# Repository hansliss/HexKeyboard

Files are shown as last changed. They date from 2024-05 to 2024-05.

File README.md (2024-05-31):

# HexKeyboard

A 25 x 25 keypad with a LED display and many features.

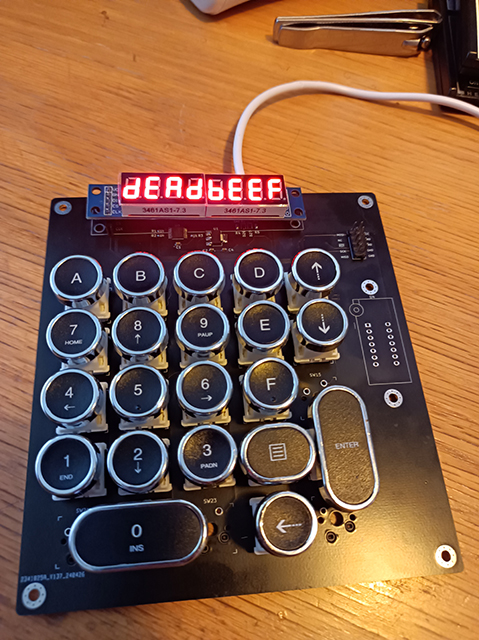
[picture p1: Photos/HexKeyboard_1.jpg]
HexKeyboard_1

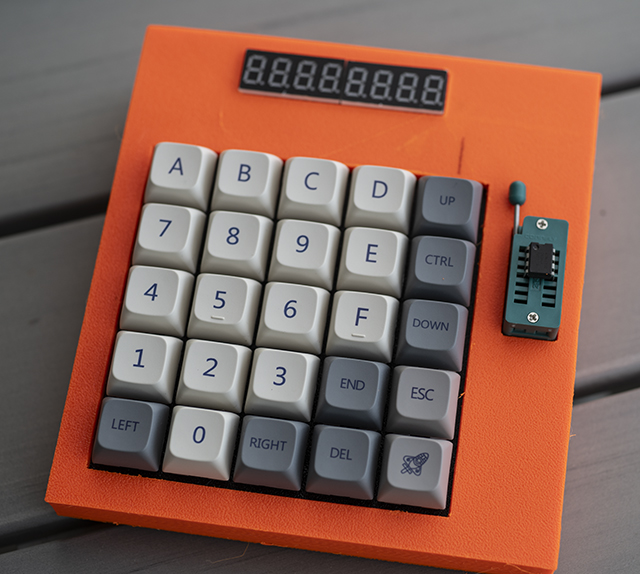
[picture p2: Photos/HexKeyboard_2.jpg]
HexKeyboard_1


* The matrix rows are on pins 4, 12, 6, 7, 23
* The matrix columns are on pins 22, 21, 20, 19, 18

The SD card holder is connected to SPI, plus

* Card Detect = PB0 / pin 17
* Chip Enable = PB4 / pin 8

Note that CD is connected to the RXLED pin, so it will probably collide with serial data.

The display is connected like this:

* CLK = 9
* CS = 10
* DIN = 11

This requires a local max7219.h with the defines modified. Just copy 

### Serial LED pins
If you want to eliminate problems with the two LED pins (see above), you can always just disable the entire functionality, by modifying USBCore.cpp (probably found here: _C:\Users\Yourname\AppData\Local\Arduino15\packages\arduino\hardware\avr\1.8.6\cores\arduino_).

Just comment out everything to do with RXLED and TXLED, and the file will be recompiled upon the next build.

### Misc
The SPI pins for the MAX7219 display aren't actually SPI pins. Still, the max7219 library just bit-bangs the protocol so it doesn't really matter.

If you add an ESP-01/ESP-01S (with the Espressif "AT" firmware, for instance), set it to use 9600 baud
on the serial interface. The default 115200 baud seems a bit too fast.

If you print the case, and want a LED indicator for the ESP-01, print out the included wifiSign model on
a resin printer using transparent resin, then drill a 3.5mm hole roughly 3.7mm below the lower edge of the
display and 13mm to the right of the right edge of the display, insert the transparent plug, and then pour black resin carefully around the symbol (preferably using a syringe and microscope) and cure it with a UV
light.

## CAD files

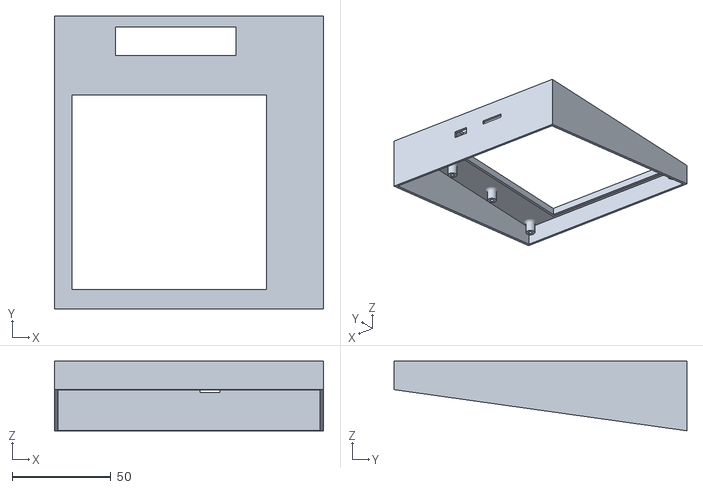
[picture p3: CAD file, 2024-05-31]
Case/case_noZIF.stl
136.2 x 148.1 x 35.2

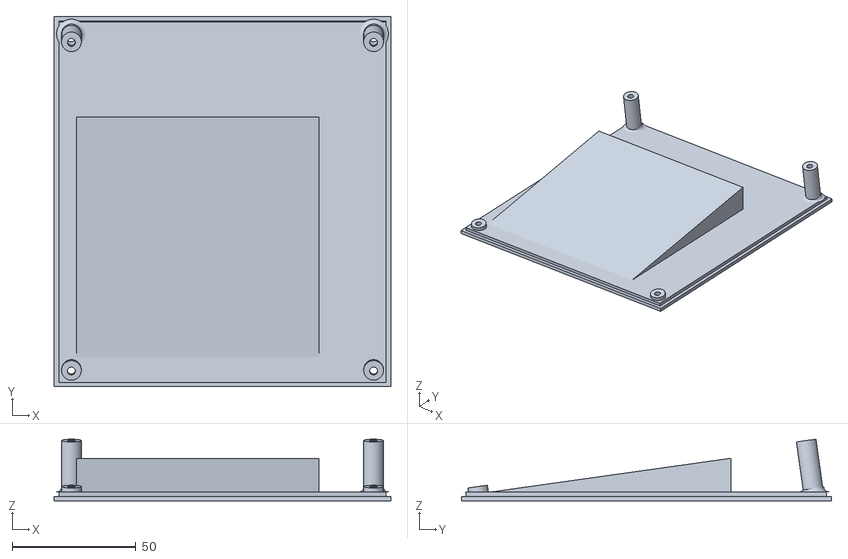
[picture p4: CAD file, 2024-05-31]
Case/caseBottom.stl
136.2 x 149.6 x 24.9

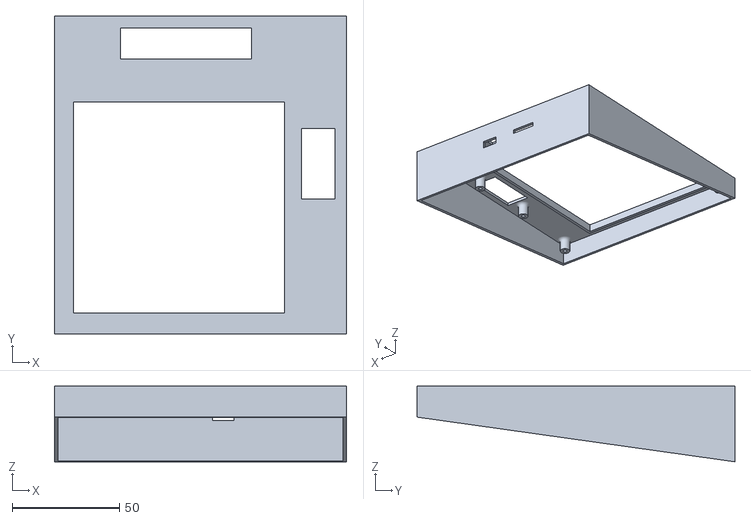
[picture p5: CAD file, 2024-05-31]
Case/case.stl
136.2 x 148.1 x 35.2

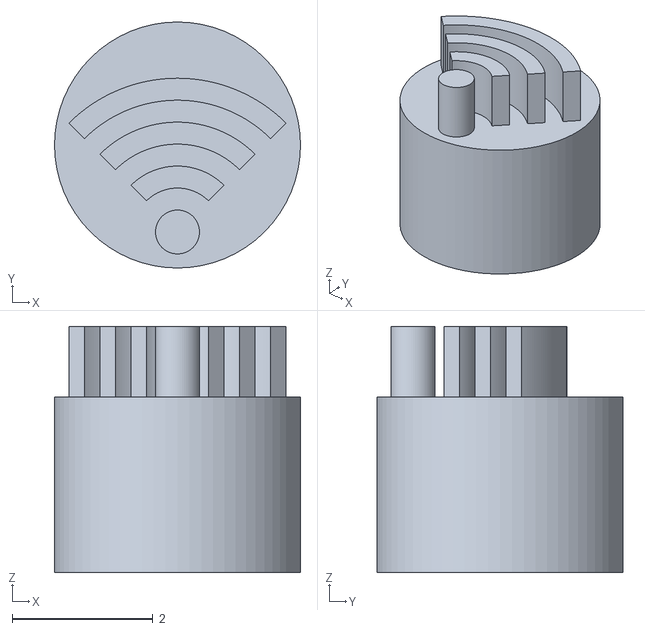
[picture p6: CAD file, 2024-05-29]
Case/wifiSign.stl
3.50 x 3.50 x 3.50

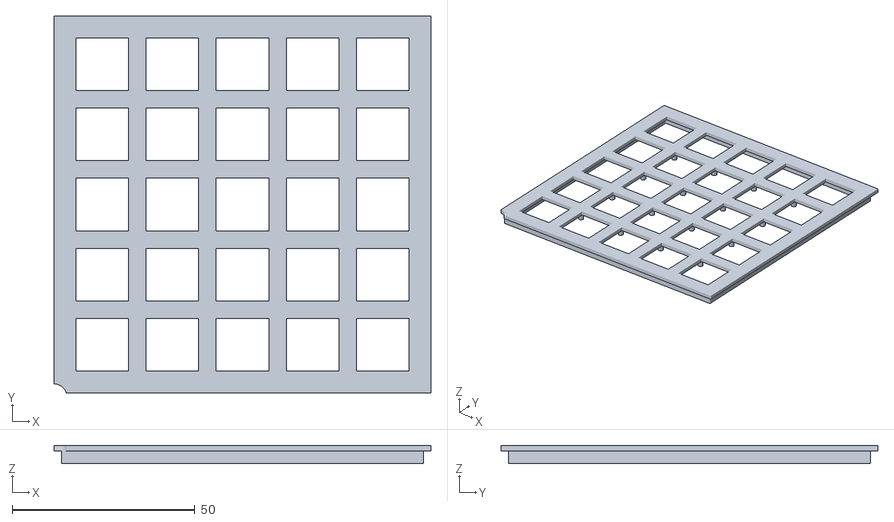
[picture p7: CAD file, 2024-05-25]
Case/faceplate.stl
103.2 x 103.3 x 5.01

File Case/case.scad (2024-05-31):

$fn=16;

include <dimensions.scad>

module screwStandoff() {
    translate([0, 0, - (caseTopStandoffHeight + caseWallThickness / 2 - 0.01)])
        union() {
            difference() {
                cylinder(r = caseTopStandoffOuterRadius, h = caseTopStandoffHeight + 0.01);
                translate([0, 0, -0.01])
                    cylinder(r = caseTopStandoffHoleRadius, h = caseTopStandoffHeight + 0.02);
            }
            translate([0, 0, caseTopStandoffHeight - caseTopStandoffSkirtRadius])
                difference() {
                    cylinder(r = caseTopStandoffOuterRadius + caseTopStandoffSkirtRadius, h = caseTopStandoffSkirtRadius);
                    
                    rotate_extrude(convexity = 10)
                        translate([caseTopStandoffOuterRadius + caseTopStandoffSkirtRadius, 0, 0])
                            circle(r = caseTopStandoffSkirtRadius);
                }
        }
}

union() {
    difference() {
        union() {
            // Top plate
            translate([caseOffsetX, caseOffsetY])
                cube([caseWidth, caseDepth, caseWallThickness], center = true);

                // 4 x top screw standoff
            translate([pcbAbsBLHoleX - pcbCX, - (pcbAbsBLHoleY - pcbCY), 0])
                screwStandoff();
            translate([pcbAbsTLHoleX - pcbCX, - (pcbAbsTLHoleY - pcbCY), 0])
                screwStandoff();
            translate([pcbAbsTRHoleX - pcbCX, - (pcbAbsTRHoleY - pcbCY), 0])
                screwStandoff();
            translate([pcbAbsBRHoleX - pcbCX, - (pcbAbsBRHoleY - pcbCY), 0])
                screwStandoff();

            // 2 x top ZIP screw standoff
            translate([pcbAbsZifTopHoleX - pcbCX, - (pcbAbsZifTopHoleY - pcbCY), 0])
                screwStandoff();
            translate([pcbAbsZifBottomHoleX - pcbCX, - (pcbAbsZifBottomHoleY - pcbCY), 0])
                screwStandoff();
        }
        // Keypad opening
        translate([pcbAbsKeypadCenterX - pcbCX, - (pcbAbsKeypadCenterY - pcbCY), 0])
            cube([caseSwitchPlateOpeningWidth, caseSwitchPlateOpeningDepth, caseWallThickness + 10], center = true);
        
        // Display opening
        translate([pcbAbsDisplayCenterX - pcbCX, - (pcbAbsDisplayCenterY - pcbCY), 00])
            cube([displayWidth, displayDepth, caseWallThickness + 0.2], center = true);
        
        // ZIF socket opening
        translate([pcbAbsZifHoleCenterX - pcbCX, -(pcbAbsZifHoleCenterY - pcbCY), 0])
            cube([caseZifHoleWidth, caseZifHoleDepth, caseWallThickness + 0.02], center = true);
    }
    
    
    translate([caseOffsetX, caseOffsetY])
    difference() {
        union() {
            translate([-(caseWidth / 2 - caseWallThickness / 2), 0, -(caseWallThickness / 2 + caseTopRimHeightUpper / 2 - 0.01 / 2)])
                cube([caseWallThickness, caseDepth, caseTopRimHeightUpper + 0.01], center = true);
            translate([(caseWidth / 2 - caseWallThickness / 2), 0, -(caseWallThickness / 2 + caseTopRimHeightUpper / 2 - 0.01 / 2)])
                cube([caseWallThickness, caseDepth, caseTopRimHeightUpper + 0.01], center = true);
            translate([0, -(caseDepth / 2 - caseWallThickness / 2), -(caseWallThickness / 2 + caseTopRimHeightUpper / 2 - 0.01 / 2)])
                cube([caseWidth, caseWallThickness, caseTopRimHeightUpper + 0.01], center = true);
            difference() {
                translate([0, (caseDepth / 2 - caseWallThickness / 2), -(caseWallThickness / 2 + caseTopRimHeightUpper / 2 - 0.01 / 2)])
                    cube([caseWidth, caseWallThickness, caseTopRimHeightUpper + 0.01], center = true);
                translate([
                    pcbAbsUsbX - pcbCX,
                    caseDepth/2,
                    -(caseWallThickness / 2 + caseTopStandoffHeight + pcbHeight + caseUsbHoleHeight / 2)
                ])
                    cube([caseUsbHoleWidth, 20, caseUsbHoleHeight], center=true);
                translate([
                    pcbAbsSdX - pcbCX,
                    caseDepth/2,
                    -(caseWallThickness / 2 + caseTopStandoffHeight + pcbHeight + caseSdHoleHeight / 2)
                ])
                    cube([caseSdHoleWidth, 20, caseSdHoleHeight], center=true);
            }
        };
        // Cut off the bottom at an angle
        translate([0, 0, -(caseTopRimHeightUpper * 3 / 2 + caseTopRimOffset / 2 + caseTopRimHeightLower)])
            rotate([-caseTopRimAngle, 0, 0])
                cube([caseWidth + 5, caseDepth + 20, caseTopRimHeightUpper * 3], center = true);
    }

    // 4 x inner rim to meet with keypad faceplate
    translate([
        pcbAbsKeypadCenterX - pcbCX + 
        -(caseSwitchPlateOpeningWidth / 2 + caseWallThickness / 2),
        -(pcbAbsKeypadCenterY - pcbCY),
        -(caseWallThickness / 2 + caseSwitchPlateOpeningRimHeight / 2 - 0.015)
    ])
        cube([
            caseWallThickness,
            caseSwitchPlateOpeningDepth + 2 * caseWallThickness,
            caseSwitchPlateOpeningRimHeight + 0.01
        ], center = true);
    translate([
        pcbAbsKeypadCenterX - pcbCX + 
        (caseSwitchPlateOpeningWidth / 2 + caseWallThickness / 2),
        -(pcbAbsKeypadCenterY - pcbCY),
        -(caseWallThickness / 2 + caseSwitchPlateOpeningRimHeight / 2 - 0.015)
    ])
        cube([
            caseWallThickness,
            caseSwitchPlateOpeningDepth + 2 * caseWallThickness,
            caseSwitchPlateOpeningRimHeight + 0.01
        ], center = true);
    translate([
        pcbAbsKeypadCenterX - pcbCX,
        -(pcbAbsKeypadCenterY - pcbCY)
        + (caseSwitchPlateOpeningDepth / 2 + caseWallThickness / 2),
        -(caseWallThickness / 2 + caseSwitchPlateOpeningRimHeight / 2 - 0.015)
    ])
        cube([
            caseSwitchPlateOpeningWidth + 2 * caseWallThickness,
            caseWallThickness,
            caseSwitchPlateOpeningRimHeight + 0.01
        ], center = true);
    translate([
        pcbAbsKeypadCenterX - pcbCX,
        -(pcbAbsKeypadCenterY - pcbCY)
        - (caseSwitchPlateOpeningDepth / 2 + caseWallThickness / 2),
        -(caseWallThickness / 2 + caseSwitchPlateOpeningRimHeight / 2 - 0.015)
    ])
        cube([
            caseSwitchPlateOpeningWidth + 2 * caseWallThickness,
            caseWallThickness,
            caseSwitchPlateOpeningRimHeight + 0.01
        ], center = true);
        

}

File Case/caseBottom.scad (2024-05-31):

$fn=128;

include <dimensions.scad>

module screwStandoffLow() {
    translate([0, 0, caseWallThickness / 2])
        rotate([caseTopRimAngle, 0, 0])
            cylinder(r=caseBottomStandoffOuterRadius, h=caseBottomShortStandoffHeight);
}

module screwStandoffHigh() {
    translate([0, 0, caseWallThickness / 2])
        rotate([caseTopRimAngle, 0, 0])
            cylinder(r=caseBottomStandoffOuterRadius, h=caseBottomTallStandoffHeight);
}

module screwHoleLow() {
    translate([0, 0, -caseWallThickness / 2])
        rotate([caseTopRimAngle, 0, 0])
            union() {
                cylinder(r=caseBottomStandoffHoleRadius, h=4 + caseWallThickness + 0.2);
                translate([0, 0, -(caseWallThickness / 2 + 0.2)])
                    cylinder(r=caseBottomStandoffInnerRadius, h=caseBottomShortStandoffHeight);
            }
}

module screwHoleHigh() {
    translate([0, 0, -caseWallThickness / 2])
        rotate([caseTopRimAngle, 0, 0])
            union() {
                cylinder(r=caseBottomStandoffHoleRadius, h=caseBottomTallStandoffHeight + caseWallThickness + 0.2);
                translate([0, 0, -(caseWallThickness / 2 + 0.2)])
                    cylinder(r=caseBottomStandoffInnerRadius, h=caseBottomTallStandoffHeight);
            }
}

difference() {
    union() {
        translate([caseOffsetX, caseOffsetY])
            union() {
                cube([caseWidth, caseDepth / cos(caseTopRimAngle), caseWallThickness], center = true);
                intersection() {
                    translate([0, 0, caseWallThickness - 0.01])
                        cube([caseWidth - (2 * caseWallThickness + 0.2), 5 + caseDepth - (2 * caseWallThickness + 0.2), caseWallThickness], center = true);
                    translate([0, 0, caseWallThickness / 2])
                        rotate([caseTopRimAngle, 0, 0])
                            cube([caseWidth - (2 * caseWallThickness + 0.2), (caseDepth - (2 * caseWallThickness + 0.2)), 50], center = true);
            }
        }
        // Keypad backing
        intersection() {
            translate([pcbAbsKeypadCenterX - pcbCX, - (pcbAbsKeypadCenterY - pcbCY), caseWallThickness * 1.5 + (caseBottomTallStandoffHeight - 1.5) / 2 - 0.01])
                cube([caseSwitchPlateOpeningWidth, caseSwitchPlateOpeningDepth, caseBottomTallStandoffHeight - 1.5], center = true);
            translate([0, 0, 0])
                rotate([caseTopRimAngle, 0, 0])
                    cube([caseWidth, caseDepth, caseBottomTallStandoffHeight], center = true);
        }
        
        // 4 x top screw standoff
        translate([(pcbAbsBLHoleX - pcbCX), - (pcbAbsBLHoleY - pcbCY) / cos(caseTopRimAngle), 0])
            screwStandoffLow();
        translate([(pcbAbsTLHoleX - pcbCX), - (pcbAbsTLHoleY - pcbCY) / cos(caseTopRimAngle), 0])
            union() {
                screwStandoffHigh();
                translate([0, 0, caseWallThickness * 1.5 - 0.01])
                difference() {
                    cylinder(r = caseBottomStandoffOuterRadius + caseBottomStandoffSkirtRadius, h = caseBottomStandoffSkirtRadius);
                    translate([0, 0, caseBottomStandoffSkirtRadius])
                        rotate_extrude(convexity = 10)
                            translate([caseBottomStandoffOuterRadius + caseBottomStandoffSkirtRadius, 0, 0])
                                circle(r = caseBottomStandoffSkirtRadius);
                }
            }
        translate([(pcbAbsTRHoleX - pcbCX), - (pcbAbsTRHoleY - pcbCY) / cos(caseTopRimAngle), 0])
            union() {
                screwStandoffHigh();
                translate([0, 0, caseWallThickness * 1.5 - 0.01])
                difference() {
                    cylinder(r = caseBottomStandoffOuterRadius + caseBottomStandoffSkirtRadius, h = caseBottomStandoffSkirtRadius);
                    translate([0, 0, caseBottomStandoffSkirtRadius])
                        rotate_extrude(convexity = 10)
                            translate([caseBottomStandoffOuterRadius + caseBottomStandoffSkirtRadius, 0, 0])
                                circle(r = caseBottomStandoffSkirtRadius);
                }
            }
        translate([(pcbAbsBRHoleX - pcbCX), - (pcbAbsBRHoleY - pcbCY) / cos(caseTopRimAngle), 0])
            screwStandoffLow();
    }
    // 4 x top screw standoff
    translate([(pcbAbsBLHoleX - pcbCX), - (pcbAbsBLHoleY - pcbCY) / cos(caseTopRimAngle), 0])
        screwHoleLow();
    translate([(pcbAbsTLHoleX - pcbCX), - (pcbAbsTLHoleY - pcbCY) / cos(caseTopRimAngle), 0])
        screwHoleHigh();
    translate([(pcbAbsTRHoleX - pcbCX), - (pcbAbsTRHoleY - pcbCY) / cos(caseTopRimAngle), 0])
        screwHoleHigh();
    translate([(pcbAbsBRHoleX - pcbCX), - (pcbAbsBRHoleY - pcbCY) / cos(caseTopRimAngle), 0])
        screwHoleLow();
    
}

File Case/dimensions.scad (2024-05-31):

facePlateSwitchHoleWidth=14.4;
facePlateSwitchHoleDepth=14.4;
facePlateThickness=1.5;
facePlateTop=5;

facePlateSwitchesX = 5;
facePlateSwitchesY = 5;

facePlateSwitchDistX=19.21;
facePlateSwitchDistY=19.22;

facePlateSwitchOuterMargin=4;

facePlateOuterMargin=2;

facePlateWidth = (facePlateSwitchesX - 1) * facePlateSwitchDistX + facePlateSwitchHoleWidth + 2 * facePlateSwitchOuterMargin;
facePlateDepth = (facePlateSwitchesY - 1) * facePlateSwitchDistY + facePlateSwitchHoleDepth + 2 * facePlateSwitchOuterMargin;

facePlateDistanceFromBLScrewHoleX = 0;
facePlateDistanceFromBLScrewHoleY = 1;

pcbAbsLeftEdgeX = 31.94;
pcbAbsTopEdgeY = 38.2;
pcbAbsRightEdgeX = 164.1;
pcbAbsBottomEdgeY = 182.34;

pcbAbsTLHoleX = 36.94;
pcbAbsTLHoleY = 43.2;

pcbAbsBLHoleX = 36.94;
pcbAbsBLHoleY = 177.34;

pcbAbsTRHoleX = 159.1;
pcbAbsTRHoleY = 43.2;

pcbAbsBRHoleX = 159.1;
pcbAbsBRHoleY = 177.34;

pcbKeySwitchCenterOffsetX = -2.54;
pcbKeySwitchCenterOffsetY = 5.08;

pcbAbsKeypadCenterX = 90.555 + pcbKeySwitchCenterOffsetX;
pcbAbsKeypadCenterY = 120.25 + pcbKeySwitchCenterOffsetY;

pcbAbsZifTopHoleX = 152.82;
pcbAbsZifTopHoleY = 83.49;

pcbAbsZifBottomHoleX = 152.82;
pcbAbsZifBottomHoleY = 126.96;

pcbAbsZifHoleCenterX = 152.9;
pcbAbsZifHoleCenterY = 105.05;

pcbAbsUsbX = 108.6025;
pcbAbsSdX = 81.94;

pcbAbsDisplayCenterX = 40 + 51.33;
pcbAbsDisplayCenterY = 48.935;

pcbCX = (pcbAbsLeftEdgeX + pcbAbsRightEdgeX) / 2;
pcbCY = (pcbAbsTopEdgeY + pcbAbsBottomEdgeY) / 2;

pcbWidth = pcbAbsRightEdgeX - pcbAbsLeftEdgeX;
pcbDepth = pcbAbsBottomEdgeY - pcbAbsTopEdgeY;
pcbHeight = 1.6;

displayWidth = 61;
displayDepth = 14.5;

caseWallThickness = 1.8;

caseSwitchMargin = 3.5;
caseSwitchPlateOpeningWidth = (facePlateSwitchesX - 1) * facePlateSwitchDistX + facePlateSwitchHoleWidth + 2 * caseSwitchMargin;
caseSwitchPlateOpeningDepth = (facePlateSwitchesY - 1) * facePlateSwitchDistY + facePlateSwitchHoleDepth + 2 * caseSwitchMargin;

caseSwitchPlateOpeningRimHeight = 3;

caseSwitchPlateOpeningPosX = pcbAbsKeypadCenterX - pcbCX;
caseSwitchPlateOpeningPosy = pcbAbsKeypadCenterY - pcbCY;

caseMarginTop = 0.2;
caseMarginBottom = 1.2;
caseMarginLeft = 1.2;
caseMarginRight = 1.2;
caseWidth = pcbWidth + caseMarginLeft + caseMarginRight + 2 * caseWallThickness;
caseDepth = pcbDepth + caseMarginTop + caseMarginBottom + 2 * caseWallThickness;
caseOffsetY = (caseMarginTop - caseMarginBottom)/2;
caseOffsetX = (caseMarginRight - caseMarginLeft)/2;

caseTopStandoffHeight = caseSwitchPlateOpeningRimHeight + facePlateTop;
caseTopStandoffHoleRadius = 1.25;
caseTopStandoffOuterRadius = 3;
caseTopStandoffSkirtRadius = 2;

caseZifHoleWidth = 15.5;
caseZifHoleDepth = 33;

caseTopRimAngle = 8;
caseTopRimOffset = tan(caseTopRimAngle) * caseDepth;
caseTopRimHeightLower = caseTopStandoffHeight + 6;
caseTopRimHeightUpper = caseTopStandoffHeight + 6 + caseTopRimOffset;

caseUsbHoleWidth = 10;
caseUsbHoleHeight = 4.5;

caseSdHoleWidth = 15.5;
caseSdHoleHeight = 2.5;

caseBottomTallStandoffHeight = 22.8;
caseBottomShortStandoffHeight = 4;
caseBottomStandoffOuterRadius = 4;
caseBottomStandoffInnerRadius = 3;
caseBottomStandoffHoleRadius = 1.6;
caseBottomStandoffSkirtRadius = caseTopStandoffSkirtRadius;

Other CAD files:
Case/faceplate.scad
Case/wifiSign.scad

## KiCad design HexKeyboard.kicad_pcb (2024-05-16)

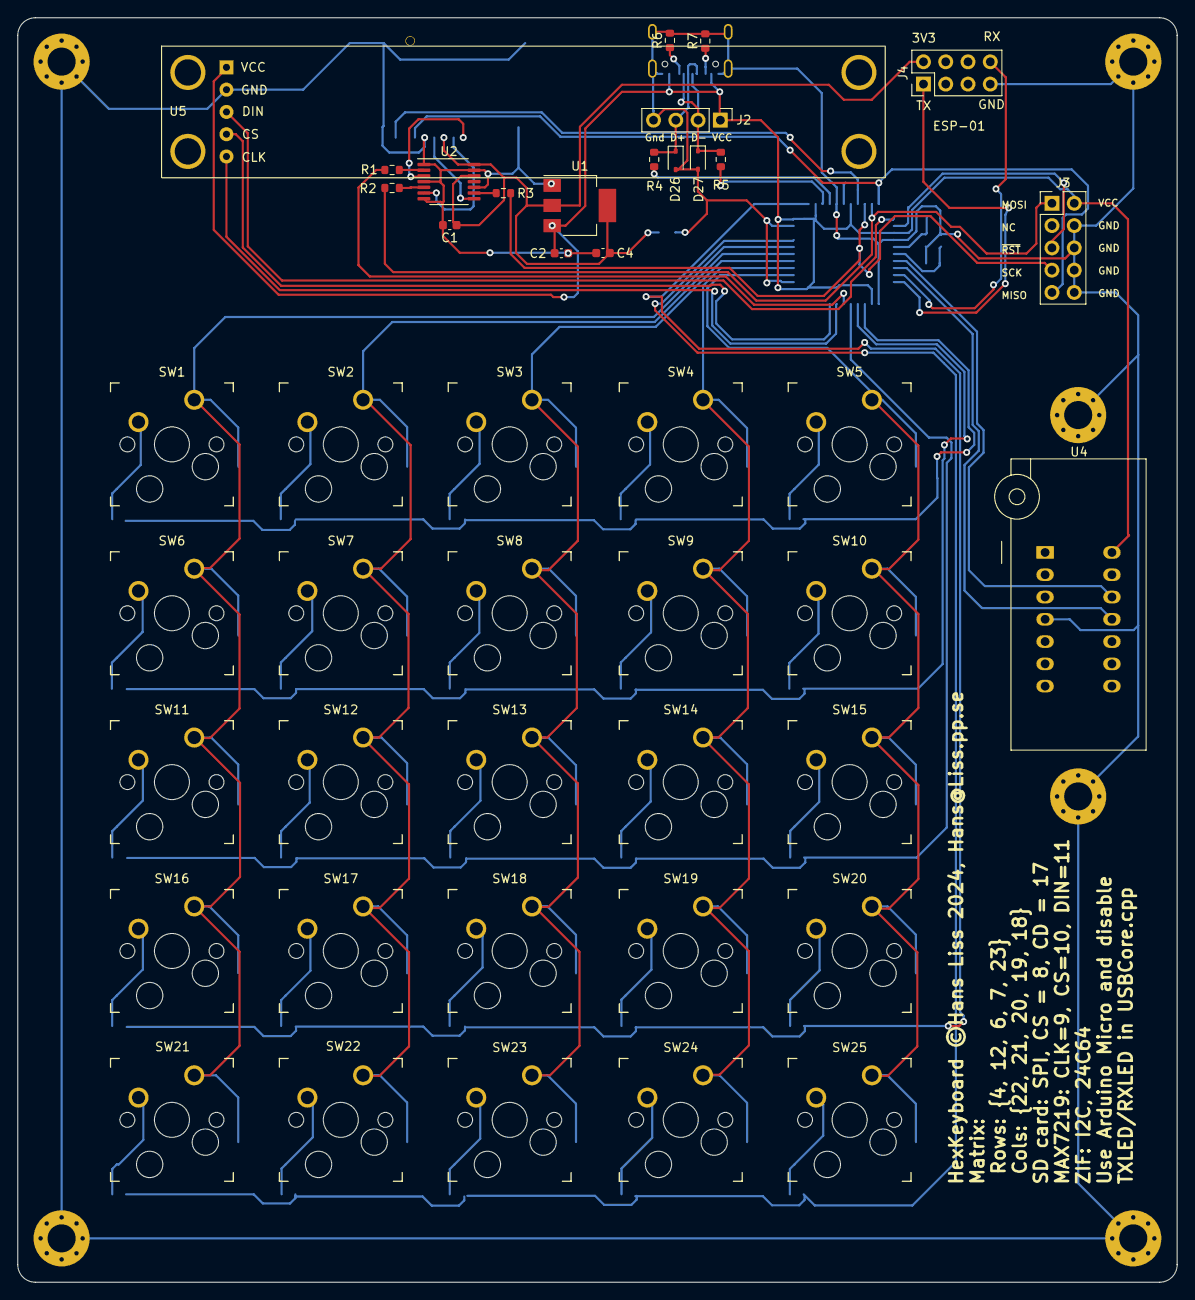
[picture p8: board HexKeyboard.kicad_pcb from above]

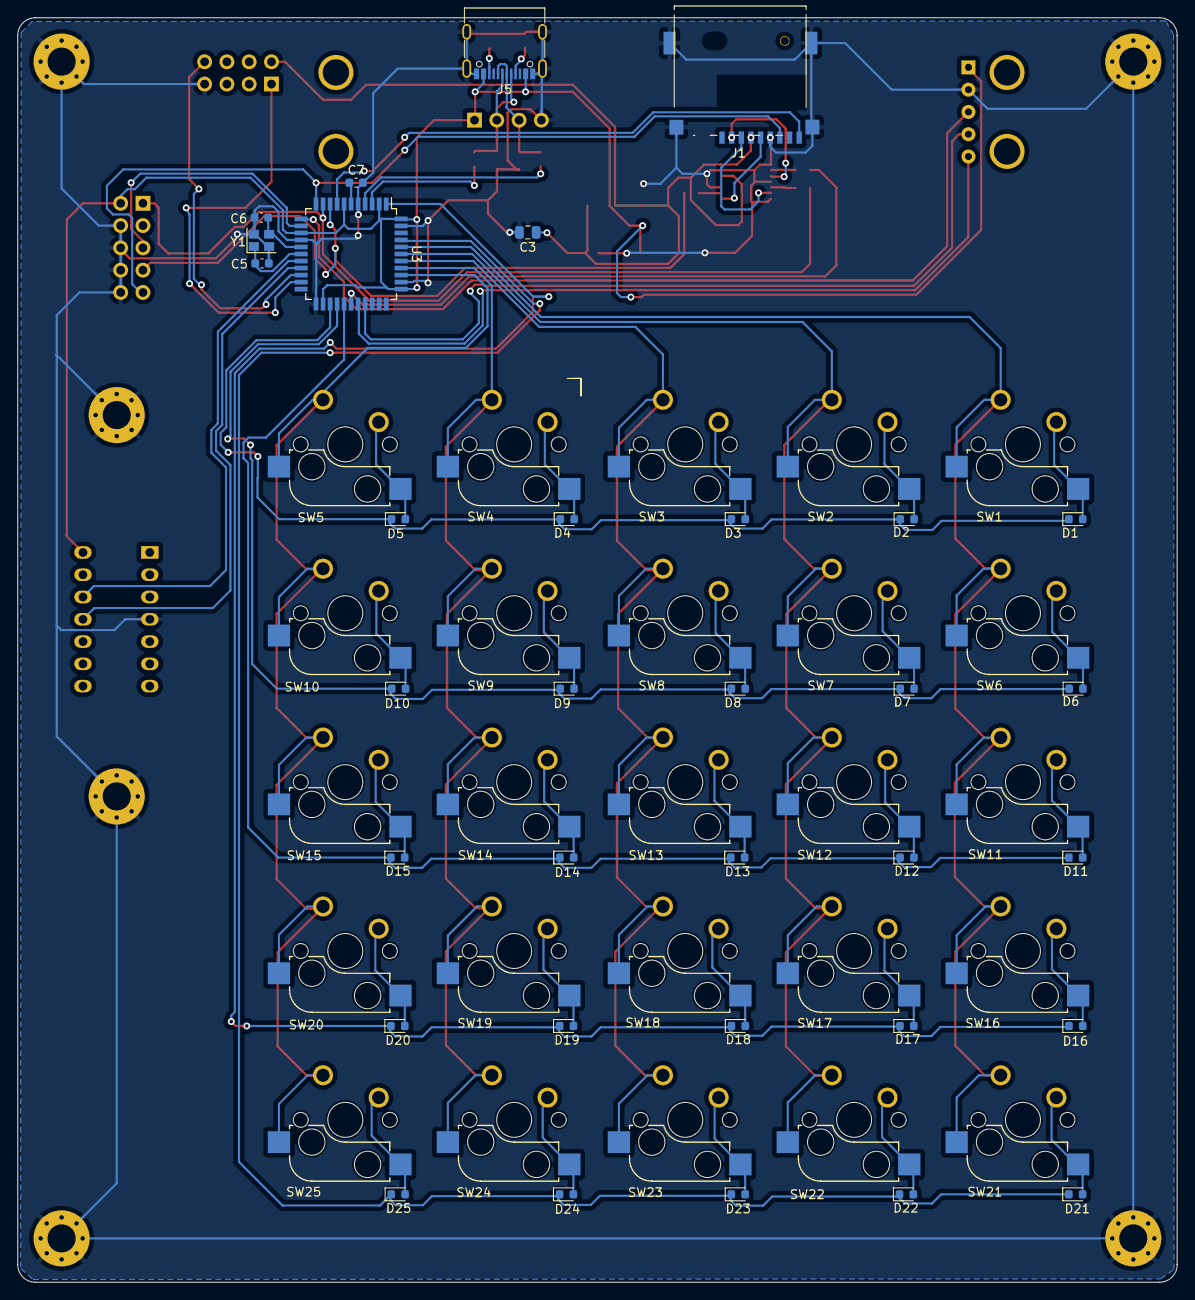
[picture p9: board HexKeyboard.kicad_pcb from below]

Board: 2 copper layers, 132.2 x 144.1 mm, 83 parts (33 on the bottom side), 66 nets.

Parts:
C1, C2, C4: 100nF; C_0603_1608Metric
C3: 10uF/10V; C_0805_2012Metric
C5, C6: 9pF; C_0603_1608Metric
C7: 1uF; C_0603_1608Metric
D1, D2, D3, D4, D5, D6, D7, D8, D9, D10, D11, D12, D13, D14, D15, D16, D17, D18, D19, D20, D21, D22, D23, D24, D25: D; D_0603_1608Metric
D26, D27: BZX384-xxx; D_SOD-323
H1, H2, H3, H4, H5, H6: MountingHole_Pad; MountingHole_3.2mm_M3_Pad_Via
J1: Micro_SD_Card; GCT_MEM2075
J2: Conn_01x04; PinHeader_1x04_P2.54mm_Vertical
J3: Conn_02x04_Odd_Even; PinHeader_2x05_P2.54mm_Vertical
J4: Conn_02x04_Odd_Even; PinHeader_2x04_P2.54mm_Vertical
J5: USB_A; USB_C_Receptacle_G-Switch_GT-USB-7010ASV
R1, R2, R3: 3k3; R_0603_1608Metric
R4, R5: 22; R_0603_1608Metric
R6, R7: 5k6; R_0603_1608Metric
SW1: SW_1; Kailh_socket_MX_optional_compatible
SW2: SW_2; Kailh_socket_MX_optional_compatible
SW3: SW_3; Kailh_socket_MX_optional_compatible
SW4: SW_4; Kailh_socket_MX_optional_compatible
SW5: SW_5; Kailh_socket_MX_optional_compatible
SW6: SW_6; Kailh_socket_MX_optional_compatible
SW7: SW_7; Kailh_socket_MX_optional_compatible
SW8: SW_8; Kailh_socket_MX_optional_compatible
SW9: SW_9; Kailh_socket_MX_optional_compatible
SW10: SW_10; Kailh_socket_MX_optional_compatible
SW11: SW_11; Kailh_socket_MX_optional_compatible
SW12: SW_12; Kailh_socket_MX_optional_compatible
SW13: SW_13; Kailh_socket_MX_optional_compatible
SW14: SW_14; Kailh_socket_MX_optional_compatible
SW15: SW_15; Kailh_socket_MX_optional_compatible
SW16: SW_16; Kailh_socket_MX_optional_compatible
SW17: SW_17; Kailh_socket_MX_optional_compatible
SW18: SW_18; Kailh_socket_MX_optional_compatible
SW19: SW_19; Kailh_socket_MX_optional_compatible
SW20: SW_20; Kailh_socket_MX_optional_compatible
SW21: SW_21; Kailh_socket_MX_optional_compatible
SW22: SW_22; Kailh_socket_MX_optional_compatible
SW23: SW_23; Kailh_socket_MX_optional_compatible
SW24: SW_24; Kailh_socket_MX_optional_compatible
SW25: SW_25; Kailh_socket_MX_optional_compatible
U1: AMS1117-3.3; SOT-223-3_TabPin2
U2: 74LVC125; TSSOP-14_4.4x5mm_P0.65mm
U3: ATmega32U4-AU; TQFP-44_10x10mm_P0.8mm
U4: AT24CS64-XHM; DIP_Socket-14_W4.3_W5.08_W7.62_W10.16_W10.9_3M_214-3339-00-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
U5: MAX7219; Display_x8_MAX7219
Y1: 16MHz; Crystal_SMD_2520-4Pin_2.5x2.0mm

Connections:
+3.3V: C1.1, C3.1, C4.1, J1.4 (VDD), J4.2, U1.2 (VO), U2.12, U2.14 (VCC)
/CD: J1.9 (DET), U3.8 (PB0)
/CE: R1.2, U3.28 (PB4)
/MISO: J1.7 (DAT0), J3.9, U3.11 (PB3)
/MOSI: J3.1, R2.2, U3.10 (PB2)
/RX: J4.8, U3.20 (PD2)
/SCK: J3.7, R3.2, U3.9 (PB1)
/SCL: U3.18 (PD0), U4.12 (SCL)
/SDA: U3.19 (PD1), U4.11 (SDA)
/TX: J4.1, U3.21 (PD3)
/~RESET: J3.5, U3.13 (~RESET)
COL0: SW1.1, SW6.1, SW11.1, SW16.1, SW21.1, U3.40 (PF1)
COL1: SW2.1, SW7.1, SW12.1, SW17.1, SW22.1, U3.39 (PF4)
COL2: SW3.1, SW8.1, SW13.1, SW18.1, SW23.1, U3.38 (PF5)
COL3: SW4.1, SW9.1, SW14.1, SW19.1, SW24.1, U3.37 (PF6)
COL4: SW5.1, SW10.1, SW15.1, SW20.1, SW25.1, U3.36 (PF7)
GND: C1.2, C2.2, C3.2, C4.2, C5.2, C6.2, C7.2, D26.2 (A), D27.2 (A), H1.1, H2.1, H3.1, H4.1, H5.1, H6.1, J1.6 (VSS), J1.10 (SHIELD), J2.4, J3.4, J3.6, J3.8, J3.10, J4.7, J5.A1 (GND), J5.A12 (GND), J5.B1 (GND), J5.B12 (GND), J5.S1 (SHIELD), R6.2, R7.2, U1.1 (GND), U2.1, U2.4, U2.7 (GND), U2.10, U2.13, U3.5 (UGND), U3.15 (GND), U3.23 (GND), U3.35 (GND), U3.43 (GND), U4.4 (GND), U5.2 (GND), Y1.2, Y1.4
unnamed: D1.2 (A), SW1.2
unnamed: D2.2 (A), SW2.2
unnamed: D3.2 (A), SW3.2
unnamed: D4.2 (A), SW4.2
unnamed: D5.2 (A), SW5.2
unnamed: D6.2 (A), SW6.2
unnamed: D7.2 (A), SW7.2
unnamed: D8.2 (A), SW8.2
unnamed: D9.2 (A), SW9.2
unnamed: D10.2 (A), SW10.2
unnamed: D11.2 (A), SW11.2
unnamed: D12.2 (A), SW12.2
unnamed: D13.2 (A), SW13.2
unnamed: D14.2 (A), SW14.2
unnamed: D15.2 (A), SW15.2
unnamed: D16.2 (A), SW16.2
unnamed: D17.2 (A), SW17.2
unnamed: D18.2 (A), SW18.2
unnamed: D19.2 (A), SW19.2
unnamed: D20.2 (A), SW20.2
unnamed: D21.2 (A), SW21.2
unnamed: D22.2 (A), SW22.2
unnamed: D23.2 (A), SW23.2
unnamed: D24.2 (A), SW24.2
unnamed: D25.2 (A), SW25.2
unnamed: D26.1 (K), J2.3, J5.A6 (D+), J5.B6 (D+), R4.2
unnamed: D27.1 (K), J2.2, J5.A7 (D-), J5.B7 (D-), R5.2
unnamed: J1.5 (CLK), U2.8
unnamed: J1.3 (CMD), U2.6
unnamed: J1.2 (DAT3/CD), U2.3
unnamed: J5.A5 (CC1), R6.1
unnamed: J5.B5 (CC2), R7.1
unnamed: R1.1, U2.2
unnamed: R2.1, U2.5
unnamed: R3.1, U2.9
unnamed: R4.1, U3.4 (D+)
unnamed: R5.1, U3.3 (D-)
unnamed: U3.29 (PB5), U5.5 (CLK)
unnamed: U3.30 (PB6), U5.4 (CS)
unnamed: U3.12 (PB7), U5.3 (DIN)
unnamed: C7.1, U3.6 (UCAP)
unnamed: C5.1, U3.17 (XTAL1), Y1.1
unnamed: C6.1, U3.16 (XTAL2), Y1.3
ROW0: D1.1 (K), D2.1 (K), D3.1 (K), D4.1 (K), D5.1 (K), U3.25 (PD4)
ROW1: D6.1 (K), D7.1 (K), D8.1 (K), D9.1 (K), D10.1 (K), U3.26 (PD6)
ROW2: D11.1 (K), D12.1 (K), D13.1 (K), D14.1 (K), D15.1 (K), U3.27 (PD7)
ROW3: D16.1 (K), D17.1 (K), D18.1 (K), D19.1 (K), D20.1 (K), U3.1 (PE6)
ROW4: D21.1 (K), D22.1 (K), D23.1 (K), D24.1 (K), D25.1 (K), U3.41 (PF0)
VCC: C2.1, J2.1, J3.2, J5.A4 (VBUS), J5.A9 (VBUS), J5.B4 (VBUS), J5.B9 (VBUS), U1.3 (VI), U3.2 (UVCC), U3.7 (VBUS), U3.14 (VCC), U3.24 (AVCC), U3.34 (VCC), U3.44 (AVCC), U4.14 (VCC), U5.1 (VCC)

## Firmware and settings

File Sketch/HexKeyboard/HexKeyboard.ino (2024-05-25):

/*
 * Hexadecimal keypad code
 *
 */

#include "KeyboardLib.h"
#include "usb_hid_keys.h"
#include <Mouse.h>
#include <SPI.h>
#include <SD.h>
#include "max7219.h"

#define DEBUG
#define ESPDEBUG
#define SCANDEBUG
#define TRISTATESTROBE
#define DOWIFI
#ifdef ESPDEBUG
#define DEBUG
#endif

struct confValues_s {
  char *name;
  char **valuep;
};

// Select the timers you're using, here ITimer4
#define USE_TIMER_1     false
#define USE_TIMER_2     false
#define USE_TIMER_3     false
#define USE_TIMER_4     true
#define USE_TIMER_5     false
#include <TimerInterrupt.h>
#include <ISR_Timer.h>

#define CSPIN 8
#define CDPIN 17

// Talk to the ESP-01's AT firmware on this port
#define ESPSERIAL Serial1
#define ESPBAUD 9600

boolean cardInserted = false;

// unsigned int rowpins[] = {0, 1, 4, 30, 29}; // Prototype
unsigned int rowpins[] = {4, 12, 6, 7, 23}; // New version
unsigned int colpins[] = {22, 21, 20, 19, 18};

#define NROWS (sizeof(rowpins) / sizeof(unsigned int))
#define NCOLS (sizeof(colpins) / sizeof(unsigned int))

#define HEXDIGIT (1<<8)
#define METAKEY (1<<9)
#define SETUP (1<<10)

const unsigned int keycode[NROWS][NCOLS] = {
  {HEXDIGIT | 'A', HEXDIGIT | 'b', HEXDIGIT | 'C', HEXDIGIT | 'd', SETUP | KEY_UP},
  {HEXDIGIT | '7', HEXDIGIT | '8', HEXDIGIT | '9', HEXDIGIT | 'E', SETUP | KEY_DOWN},
  {HEXDIGIT | '4', HEXDIGIT | '5', HEXDIGIT | '6', HEXDIGIT | 'F', -1},
  {HEXDIGIT | '1', HEXDIGIT | '2', HEXDIGIT | '3', SETUP | KEY_PROPS, SETUP | KEY_ENTER},
  {-1, HEXDIGIT | '0', -1, SETUP | KEY_LEFT, -1}
};

#define BUFLEN 64

MAX7219 max7219;

char tmpbuf[BUFLEN];


void setup() {
  TXLED0;
  RXLED0;
  pinMode(CSPIN, OUTPUT);
  digitalWrite(CSPIN, HIGH);
  pinMode(CDPIN, INPUT_PULLUP);

  initKeyboard();
  initHexpad();
  initHID();

  max7219.Begin();
  max7219.DisplayText("REAdY", 1);
  Mouse.begin();
#ifdef DEBUG
  Serial.begin(115200);
  while (!Serial){
    ;
  }
#endif
  File infile;
}

void readFromSD() {
  if (SD.begin(CSPIN)) {
#ifdef DOWIFI
    checkWifi();
#endif
#ifdef DEBUG
  } else {
    Serial.println("SD initialization failed");
#endif
  }
}

void moveMouse() {
  Mouse.move(random(2) - 1, random(2) - 1);
  delay(200);
}

void loop() {
  static unsigned long stimeMillis = millis();
  unsigned long nowMillis = millis();
  long diff = nowMillis - stimeMillis;
  if (nowMillis < stimeMillis) {
    diff = nowMillis + (UINT32_MAX - stimeMillis);
  }

  boolean newCardInserted = (digitalRead(CDPIN) == LOW);
  if (newCardInserted && !cardInserted) {
#ifdef DEBUG
    Serial.println("Card inserted");
    readFromSD();
#endif
  } else if (!newCardInserted && cardInserted) {
#ifdef DEBUG
    Serial.println("Card removed");
#endif
  }
  cardInserted = newCardInserted;

  //checkForKeyboardChanges();

  checkHexDigitQueue();

  if (diff > random(3000) + 2000) {
//    if (random(100) > 60) {
      moveMouse();
//    }
    stimeMillis = nowMillis;
  }
  delay(1);
}

#pragma region "Hexpad code"
unsigned char hexDigitQueue[32];
int hexDigitQueueStart=0;
int hexDigitQueueNext=0;

void addToHexDigitQueue(unsigned char digit) {
  hexDigitQueue[hexDigitQueueNext] = digit;
  hexDigitQueueNext = (hexDigitQueueNext + 1) % sizeof(hexDigitQueue);
  if (hexDigitQueueNext == hexDigitQueueStart) {
    hexDigitQueueStart = (hexDigitQueueStart + 1) % sizeof(hexDigitQueue);
  }
}

unsigned char fetchFromHexDigitQueue() {
  int retval = -1;
  noInterrupts();
  if (hexDigitQueueStart != hexDigitQueueNext) {
    retval = hexDigitQueue[hexDigitQueueStart];
    hexDigitQueueStart = (hexDigitQueueStart + 1) % sizeof(hexDigitQueue);
  }
  interrupts();
  return retval;
}

boolean hasMoreHexDigits() {
  return  (hexDigitQueueStart != hexDigitQueueNext);
}

int hexpad_mode = 0;
int hexpad_worddigits = 2;
int hexpad_linelength = 16;
char *hexpad_prefix = "0x";
char *hexpad_delimiter = ", ";
char *hexpad_eol = ",\n";

unsigned char hexDigits[9];

void initHexpad() {
  memset(hexDigits, ' ', sizeof(hexDigits));
  hexDigits[sizeof(hexDigits) - 1] = '\0';
}

void checkHexDigitQueue() {
  while (hasMoreHexDigits()) {
    unsigned char newHexDigit = fetchFromHexDigitQueue();
    memmove(hexDigits, hexDigits + 1, sizeof(hexDigits) - 1);
    hexDigits[7] = newHexDigit;
    hexDigits[8] = '\0';
    max7219.DisplayText(hexDigits, 1);
#ifdef DEBUG
    // Serial.println(String("Hex digit: ") + (char)(keycode[row][col] & 0xFF));
#endif
    hexpad_addDigit(newHexDigit);
  }
}

void hexpad_addDigit(unsigned char digit) {
  static int currentDigits = 0;
  static int currentWords = 0;
  static char wordBuf[9];
  wordBuf[currentDigits] = toupper(digit);
  currentDigits++;
  wordBuf[currentDigits] = '\0';
  if (currentDigits >= hexpad_worddigits) {
    if (currentWords > 0) {
#ifdef DEBUG
      Serial.print(hexpad_delimiter);
#endif
      // output hexpad_delimiter
    }
#ifdef DEBUG
    Serial.print(hexpad_prefix);
    Serial.print(wordBuf);
#endif
    // output prefix
    // output word
    currentDigits = 0;
    currentWords++;
    if (currentWords >= hexpad_linelength) {
#ifdef DEBUG
      Serial.print(hexpad_eol);
#endif
      // output hexpad_eol
      currentWords = 0;
    }
  }
}

#pragma endregion "Hexpad code"

#pragma region "Keyboard scanning code"
#define STABILIZE_STROBE_DELAY 5
#define SCANNER_INTERVAL_MS 1

// Keep track of key state changes, in the easiest way possible
uint8_t keydown[NROWS][NCOLS];
uint8_t oldkeydown[NROWS][NCOLS];

unsigned long debounceDelay = 10;    // the debounce time; increase if the output flickers

void initKeyboard() {
  for (int i=0; i<NCOLS; i++) {
    pinMode(colpins[i], INPUT_PULLUP);
  }
  for (int i=0; i<NROWS; i++) {
#ifdef TRISTATESTROBE
    pinMode(rowpins[i], INPUT);
#else
    pinMode(rowpins[i], OUTPUT);
    digitalWrite(rowpins[i], HIGH);
#endif
  }

  memset(keydown, 0, sizeof(keydown));
  memset(oldkeydown, 0, sizeof(oldkeydown));

  // Init timer ITimer4
  ITimer4.init();
  // Interval in unsigned long millisecs
  ITimer4.attachInterruptInterval(SCANNER_INTERVAL_MS, scanKeyboard);
}

void handleSetupKey(int keycode) {
  switch(keycode) {
    case KEY_PROPS:
#ifdef DEBUG
      Serial.println("Enter setup");
#endif
    break;
  case KEY_UP:
#ifdef DEBUG
      Serial.println("Menu Up");
#endif
    break;
  case KEY_DOWN:
#ifdef DEBUG
    Serial.println("Menu Down");
#endif
    break;
  case KEY_LEFT:
#ifdef DEBUG
    Serial.println("Menu exit");
#endif
    break;
  case KEY_ENTER:
#ifdef DEBUG
    Serial.println("Menu confirm");
#endif
    break;
  default:
#ifdef DEBUG
    Serial.print("Unknown setup key pressed: ");
    Serial.println(keycode);
#endif
    break;
  }
}

void scanKeyboard() {
  // We keep a local debouncing state array here
  static uint8_t debounce[NROWS][NCOLS];

  noInterrupts();
  for (int row = 0; row < NROWS; row++) {
#ifdef TRISTATESTROBE
    pinMode(rowpins[row], OUTPUT);
#endif
    digitalWrite(rowpins[row], LOW);
    // Wait a bit to let it settle
    delayMicroseconds(STABILIZE_STROBE_DELAY);

    for (int col = 0; col < NCOLS; col++) {
      if (digitalRead(colpins[col]) == LOW) {
        switch (debounce[row][col]) {
          // We debounce by just waiting one extra cycle (SCANNER_INTERVAL) and making
          // sure the key is still pressed
          case 0:
            debounce[row][col]++;
            break;
          case 1:
            debounce[row][col]++;
            keydown[row][col] = 1;
#ifdef SCANDEBUG
            Serial.println(String("Key down : (") + col + "," + row + ")");
#endif
            break;
          case 2:
            break;
        }
      } else {
        debounce[row][col] = 0;
        keydown[row][col] = 0;
      }
    }
#ifdef TRISTATESTROBE
    pinMode(rowpins[row], INPUT);
#else
    digitalWrite(rowpins[row], HIGH);
#endif
  }
  checkForKeyboardChanges();
  interrupts();
}

// Scan through the key state array, compare to the saved state from last run, and
// generate events. Some special cases are handled internally
void checkForKeyboardChanges() {
  static boolean isChanged = false;
  resetKeys();
  for (unsigned int col = 0; col < NCOLS; col++) {
    for (unsigned int row = 0; row < NROWS; row++) {
      if (keydown[row][col] && !oldkeydown[row][col]) {
        // Key Down event
        if (keycode[row][col] != -1) {
          if (keycode[row][col] & HEXDIGIT) {
            addToHexDigitQueue(keycode[row][col] & 0xFF);
          } else if (keycode[row][col] & METAKEY) {
            addMeta(keycode[row][col] & 0xFF);
            isChanged = true;
          } else if (keycode[row][col] & SETUP) {
            // TODO: Add a keystroke queue for setup keys
            // handleSetupKey(keycode[row][col] & 0xFF);
          } else {
            addKeyToBuffer(keycode[row][col]);
            isChanged = true;
          }
        }
      } else if (!keydown[row][col] && oldkeydown[row][col]) {
        if (keycode[row][col] != -1 && !(keycode[row][col] & HEXDIGIT)) {
          isChanged = true;
        }
      }
      // Update the saved state
      oldkeydown[row][col] = keydown[row][col];
    }
  }
  if (isChanged) {
    // TODO: Move the HID code outside the interrupt handler
    sendKeys();
  }
}
#pragma endregion "Keyboard scanning code"

#pragma region "HID code"

const byte keyLimit = 6;
byte keyPlace = 0;
uint8_t keyBuf[keyLimit];
uint8_t nullBuf[keyLimit];
uint8_t meta = 0;

void addMeta(uint8_t metacode) {
  meta |= metacode;
}

void addKeyToBuffer(uint8_t key) {
  if (keyPlace < keyLimit) {
    keyBuf[keyPlace++] = key;
  }
}

void sendKeys() {
  sendBuffer(meta, keyBuf);
}

void sendBuffer(uint8_t meta, uint8_t keyBuf[]) {
  sendKeyBuffer(meta, keyBuf);
  resetKeys();
}

void resetKeys() {
  memset(keyBuf, 0, sizeof(keyBuf));
  memset(nullBuf, 0, sizeof(nullBuf));
  keyPlace = 0;
  meta = 0;
}

#pragma endregion "HID code"

#pragma region "Config file code"

void trimEOL(char *str) {
  while (strlen(str) > 0 && (str[strlen(str) - 1] == '\n' || str[strlen(str) - 1] == '\r')) {
    str[strlen(str) - 1] = '\0';
  }
}

boolean readLine(File infile, char *buf, int bufsize) {
  int n = 0;
  int sz = infile.available();
  while (sz && n < bufsize - 1) {
    buf[n] = infile.read();
    sz--;
    if (buf[n] == '\n') {
      break;
    }
    n++;
  }
  buf[n] = '\0';
  trimEOL(buf);
  return (n > 0);
}

char *split(char *string, char delim) {
  char *second = string;
  while (*second && *second != delim) {
    second++;
  }
  if (*second) {
    char *tmp = second;
    while(tmp > string && *tmp == delim || isWhitespace(*tmp)) {
      *(tmp--) = '\0';
    }
    do {
      *(second++) = '\0';
    } while (*second && isWhitespace(*second));
  }
  return second;
}

boolean readConfig(char *filename, struct confValues_s *confValues, int nConfValues) {
  boolean success = false;
  File infile;
  if ((infile = SD.open(filename)) != 0) {
    for (int i=0; i<nConfValues; i++) {
      if ((*(confValues[i].valuep)) != NULL) {
        free(*(confValues[i].valuep));
        *(confValues[i].valuep) = NULL;
      }
    }
    while (readLine(infile, tmpbuf, sizeof(tmpbuf))) {
      char *value = split(tmpbuf, '=');
      if (value) {
        for (int i=0; i<nConfValues; i++) {
          if (!strcasecmp(confValues[i].name, tmpbuf)) {
            *(confValues[i].valuep) = strdup(value);
          }
        }
      }
    }
    infile.close();
  }
  return success;
}
#pragma endregion "Config file code"

#pragma region "WiFi code"

#ifdef DOWIFI
char *ssid = NULL;
char *passphrase = NULL;
char *hostname = NULL;

struct confValues_s wiFiConf[] = {
  {"ssid", &ssid},
  {"passphrase", &passphrase},
  {"hostname", &hostname}
};

const int nWiFiConf = 3;

void checkWifi() {
  readConfig("wifi.cnf", wiFiConf, nWiFiConf);
  if (ssid && passphrase) {
    connectWiFi();
  }
}

boolean expect(char *expected1, char *expected2, char *failString, int timeout) {
  int resppos = 0;
  memset(tmpbuf, 0, sizeof(tmpbuf));
  long startmillis=millis();
  while (1) {
    if (millis() - startmillis > timeout * 1000) {
      break;
    }
    while (ESPSERIAL.available() > 0) {
      char c = ESPSERIAL.read();
      if (resppos == sizeof(tmpbuf) - 1) {
        memmove(tmpbuf, tmpbuf + 1, sizeof(tmpbuf) - 1);
        resppos--;
      }
      tmpbuf[resppos++] = c;
#ifdef ESPDEBUG
      Serial.print(c);
#endif
      if (strstr(tmpbuf, expected1) != NULL || (expected2 != NULL && strstr(tmpbuf, expected2) != NULL)) {
        return true;
      } else if (failString != NULL && strstr(tmpbuf, failString) != NULL) {
#ifdef ESPDEBUG
        Serial.println("Received fail response");
#endif
        return false;
      }
    }
  }
#ifdef ESPDEBUG
  Serial.println("Timeout");
#endif
  return false;
}

boolean executeCommand(char *command, char *success, char *success2, char *failure, int timeout, int retries, int retryDelay) {
  for (int i = 0; i < retries; i++) {
    ESPSERIAL.print(command);
    ESPSERIAL.print("\r\n");
    if (expect(success, success2, failure, timeout)) {
      return true;
    } else {
      delay(retryDelay * 1000);
    }
  }
  return false;
}

boolean connectWiFi() {
  boolean retval = false;
  boolean ok = false;
  ESPSERIAL.begin(ESPBAUD);
  if (!ssid || !passphrase) {
    return false;
  }

  if (!executeCommand("AT+CWSTATE?", ssid, NULL, NULL, 2, 2, 2)) {
#ifdef DEBUG
    Serial.println("Not connected. Reconnecting.");
#endif
    expect("OK\r\n", NULL, NULL, 3);
    if (!executeCommand("AT+RST", "OK\r\n", NULL, NULL, 3, 5, 2)) {
      return false;
    }
#ifdef ESPDEBUG
    else {
      expect("ready", "GOT IP\r\n", NULL, 9);
      Serial.println("Module Reset");
    }
#endif
    if (!executeCommand("AT+CWMODE=1", "OK\r\n", NULL, NULL, 3, 5, 2)) {
      return false;
    }
#ifdef ESPDEBUG
    else {
      Serial.println("Mode set");
    }
#endif
    if (!executeCommand("AT+CWLAP", ssid, NULL, NULL, 10, 5, 2)) {
      return false;
    }
#ifdef ESPDEBUG
    else {
      Serial.println("SSID found");
    }
#endif
    expect("OK", NULL, NULL, 2);
    if (!executeCommand("AT+SYSSTORE=1", "OK\r\n", NULL, NULL, 4, 1, 2)) {
      return false;
    }
#ifdef ESPDEBUG
    else {
      Serial.println("SYSSTORE set");
    }
#endif
    if (!executeCommand("AT+CWAUTOCONN=1", "OK\r\n", NULL, NULL, 3, 5, 2)) {
      return false;
    }
#ifdef ESPDEBUG
    else {
      Serial.println("AUTOCONN set");
    }
#endif
    if (!executeCommand("AT+CWRECONNCFG=2,0", "OK\r\n", NULL, NULL, 3, 5, 2)) {
      return false;
    }
#ifdef ESPDEBUG
    else {
      Serial.println("RECONNCFG set");
    }
#endif
    if (!executeCommand("AT+CWDHCP=1,3", "OK\r\n", NULL, NULL, 3, 5, 2)) {
      return false;
    }
#ifdef ESPDEBUG
    else {
      Serial.println("DHCP config set");
    }
#endif
    if (hostname) {
      sprintf(tmpbuf, "AT+CWHOSTNAME=\"%s\"", hostname);
      if (!executeCommand(tmpbuf, "OK\r\n", NULL, NULL, 5, 5, 2)) {
        return false;
      }
#ifdef ESPDEBUG
      else {
        Serial.println("Hostname set");
      }
#endif
    }
    sprintf(tmpbuf, "AT+CWJAP=\"%s\",\"%s\"", ssid, passphrase);
    if (!executeCommand(tmpbuf, "OK\r\n", NULL, NULL, 10, 10, 5)) {
      return false;
    }
#ifdef ESPDEBUG
    else {
      Serial.println("Connected");
    }
#endif
    if (!executeCommand("AT+CIPSNTPCFG=1,0,\"ntp.se\"", "OK\r\n", NULL, NULL, 10, 1, 5)) {
      return false;
    }
#ifdef ESPDEBUG
    else {
      Serial.println("SNTP configured");
    }
#endif
#ifdef DEBUG
    Serial.println("Connected to WiFi");
#endif
  } else {
#ifdef DEBUG
    Serial.println("WiFi already connected");
#endif
  }
}
#endif
#pragma endregion "WiFi code"

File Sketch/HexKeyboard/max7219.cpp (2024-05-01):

/*
* The MIT License (MIT)
*
* Copyright (c) JEMRF
*
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
********************************************************************************
*
* Module     : max7219.cpp
* Author     : Jonathan Evans
* Description: MAX7219 LED Display Driver
*
* The MAX7219/MAX7221 are compact, serial input/output common-cathode display drivers that interface
* microprocessors (µPs) to 7-segment numeric LED displays of up to 8 digits, bar-graph displays, or 64 
* individual LEDs
* Datasheet  : https://datasheets.maximintegrated.com/en/ds/MAX7219-MAX7221.pdf
*
* Library Description
*
*  - This library implements the 7-segment numeric LED display of 8 digits 
*  - The host communicates with the MAX7219 using three signals: CLK (pin 10), CS (pin 11), DIN (pin 12). 
*  - Pins can be configured in max7219.h
*  - The MAX7219 is a SPI interface
*  - This lbtary uses the buitbang method for communication with the MAX7219 
*
* Usage
*
* Three methods are exposed for use:
*  
*  1. Begin
*  This method initializes communication, takes the display out of test mode, clears the screen and sets intensity.
*  Intensity is set at maximum but can be coinfigured in max7219.h
*  
*  2. DisplayChar(Digit, Value, DP)
*  This method displays a single value (charachter) in position DIGIT (0=right most digit, 7=left most digit)
*  
*  3. DisplayText(Text, Justify)
*  This method displays a text string (Text) either right justified (Justify=0) ot left justified (Justify=1) 
*/

#include "max7219.h"

MAX7219:: MAX7219(void)
{
  pinMode(MAX_DIN, OUTPUT);
  pinMode(MAX_CS, OUTPUT);
  pinMode(MAX_CLK, OUTPUT);
}

void MAX7219::MAX7219_ShutdownStart (void)
{
  MAX7219_Write(REG_SHUTDOWN, 0);                     
}

void MAX7219:: MAX7219_DisplayTestStart (void)
{
  MAX7219_Write(REG_DISPLAY_TEST, 1);                 
}

void MAX7219::Clear(void) {
    
    for(int i=0;i<8;i++) {
        MAX7219_Write(i+1,0x00);
    }
}

void MAX7219::MAX7219_DisplayTestStop (void)
{
  MAX7219_Write(REG_DISPLAY_TEST, 0);                 
}

void MAX7219::MAX7219_SetBrightness (char brightness)
{
  brightness &= 0x0f;                                 
  MAX7219_Write(REG_INTENSITY, brightness);           
}

unsigned char MAX7219::MAX7219_LookupCode (char character, unsigned int dp)
{
  int i;
  unsigned int d=0;
 if (dp) d=1;  
  if (character>=35 && character<=44) {
    character+=13;
    d=1;
  }
  for (i = 0; MAX7219_Font[i].ascii; i++)              
    if (character == MAX7219_Font[i].ascii){
      if (d){
        d=MAX7219_Font[i].segs;
        d |= (1<<7);
        return (d);                                    
        }
      else{
        return MAX7219_Font[i].segs;                    
      }
    }
      
  return 0;                                             
}

void MAX7219::DisplayText(char *text, int justify){
  int decimal[16];
  char trimStr[16] = "";
  int x,y=0;
  int s;
  
  s=strlen(text);
  if (s>16) s=16;
  for (x=0;x<s;x++){
    if (text[x]=='.'){
      decimal[y-1]=1;
      }
    else{
      trimStr[y]=text[x];
      decimal[y]=0;
      y++;
     }
  }
  if (y>8) y=8;
  for (x=0;x<y;x++){
      if (justify==0)
        DisplayChar((int)(y-x+7-y),trimStr[x], decimal[x]);    
      if (justify==1){
        DisplayChar((int)(y-x+7-y-(8-y)),trimStr[x], decimal[x]);    
        
      }
  }
}

void MAX7219::MAX7219_Write(volatile byte opcode, volatile byte data) {
    digitalWrite(MAX_CS,LOW);
    shiftOut(MAX_DIN,MAX_CLK,MSBFIRST,opcode);
    shiftOut(MAX_DIN,MAX_CLK,MSBFIRST,data);
    digitalWrite(MAX_CS,HIGH);
}    

void MAX7219::DisplayChar(int digit, char value, bool dp) {
      MAX7219_Write(digit+1,MAX7219_LookupCode(value, dp));
}

static void MAX7219::MAX7219_ShutdownStop (void)
{
  MAX7219::MAX7219_Write(REG_SHUTDOWN, 1);   
}
 
void MAX7219::Begin()
{ 
  digitalWrite(MAX_CS,HIGH);
  MAX7219_Write(REG_SCAN_LIMIT, 7);                   
  MAX7219_Write(REG_DECODE, 0x00);                    
  MAX7219_ShutdownStop();                             
  MAX7219_DisplayTestStop();                          
  Clear();                                    
  MAX7219_SetBrightness(INTENSITY_MAX);               
}

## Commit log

2024-04-25 Initial import
    [HexKeyboard.kicad_pcb, HexKeyboard.kicad_sch, HexKeyboard.sch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]
2024-04-25 Cleaned up libraries Added Display Switched to USB-C
    [HexKeyboard.kicad_pcb, HexKeyboard.kicad_sch]
2024-04-25 Filled up matrix to 5x5 Started on layout
    [HexKeyboard.kicad_pcb, HexKeyboard.kicad_sch]
2024-04-25 Finished layout and routing
    [HexKeyboard.kicad_pcb, HexKeyboard.kicad_sch]
2024-04-25 Connected mounting holes to Gnd Added filled zone
    [HexKeyboard.kicad_pcb, HexKeyboard.kicad_sch]
2024-04-25 Switched to the correct MicroSD holder
    [HexKeyboard.kicad_pcb, HexKeyboard.kicad_sch]
2024-05-01 Moved datasheets to Docs/ Added simple sketch to test display, keyboard, basic HID code etc. Added some documentation in README.md Added Gerbers for first prototype
2024-05-06 Footprint for SD holder updated. SD holder turned 180 deg USB connector moved out a bit
    [HexKeyboard.kicad_pcb]
2024-05-07 Added serial port. Added new pin numbers to sketch
    [HexKeyboard.kicad_pcb, HexKeyboard.kicad_sch]
2024-05-08 Added a faceplate for the hotswap switches.
    [faceplate.scad, faceplate.stl]
2024-05-11 Complete rudimentary case design added
    [case.scad, case.stl, caseBottom.scad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]
2024-05-11 Minor cleanup of the scad files. .gitignore and cleanup of files
    [case.scad, case.stl, caseBottom.scad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]
2024-05-16 Fixed some erroneous pin numbers
    [HexKeyboard.kicad_pcb]
2024-05-19 Added a slanted platform to the case bottom, for holding a damper against the back of the keypad. Added a comment about ESP-01 communication
    [caseBottom.scad, caseBottom.stl]
2024-05-25 New case models
    [case.stl, caseBottom.stl, case_noZIF.stl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]
2024-05-29 Added more info to the README.md Added wifiSign 3d model
    [wifiSign.scad, wifiSign.stl]
2024-05-31 Changed the case to fix the margins around the PCB.
    [case.scad, case.stl, caseBottom.scad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]

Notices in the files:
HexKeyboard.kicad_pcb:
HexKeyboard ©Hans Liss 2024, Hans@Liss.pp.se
